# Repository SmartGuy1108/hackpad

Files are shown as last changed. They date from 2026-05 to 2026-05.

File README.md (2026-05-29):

# hackpad

My Hackpad is a 9 key macropad that uses 9 keyboard switches, a 0.96in oled screen, a xiao rp2040, 9 rgb leds, and a ATtiny85 for the leds. I made a PCB for this which can be found in the repo. It includes the gerber and drill files. My total price for this project was around $40 I used AliExpress to source the components for cheap and I used JLPCB for the PCB. The point of this was to make a maacropad that was cool and could be used for custom purposes instead of using the defualt layout. It works by making the Xiao do all the proccesing for the keys and the ATtiny doing all the led controls while being powered by the Xiao. I considered adding a usb C port for the ATtiny but decided against it to keep it all connected using one usb C so it looks clean. The total cost was around $48 I made a custom case that has a big hole for all the 9 keys because I didn't want they keycaps to get stuck on the lid. Here is the link to the OnShape project: https://cad.onshape.com/documents/e6c91fd51721781c7e785687/w/94b65f4af145f619cdb675ed/e/b2b440a0c79fd98d3f7bde3f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. The lid connects to the body using "rails" in the body. I also added a hole on the top for the OLED. I added circles on each corner of the pcb groove to make sure it stayed in place. Here is a image of the case: 

          






Some Items I used were:

|#  |Component |Quantity|Price |Supplier  |Link |
|---|---|---|---|---|---|
|1  |XDA Profile PBT Blank Black Keycaps (MX compatible 10pcs)|10 |included|AliExpress|https://www.aliexpress.us/item/3256805328092200.html |
|2  |ATtiny85-20PU DIP-8 AVR Microcontroller |1 |included|AliExpress|https://www.aliexpress.us/item/3256808555620766.html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  |
|3  |SSD1306 0.96in 128x64 OLED Display (I2C white 3pcs) |1 |included|AliExpress|https://www.aliexpress.us/item/3256805899077405.html |
|4  |WS2812B 5mm RGB Through-hole LED (5V diffused 10pcs) |9 |included|AliExpress|https://www.aliexpress.us/item/3256806040849067.html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|
|5  |Outemu Blue 3-Pin MX Switches (10pcs) |10 |included|AliExpress|https://www.aliexpress.us/item/3256803795058460.html |
|6  |Custom PCB 2 layer black 5pcs (JLCPCB) |5 |$9.30 |JLCPCB |N/A |
|7  |AliExpress Subtotal |- |- |$11.02 |- |
|8  |AliExpress Total |- |- |$11.02 |- |
|9  |PCB + Shipping |- |- |$12.00 |- |
|10 |Grand Total |- |- |$23.02 |- |

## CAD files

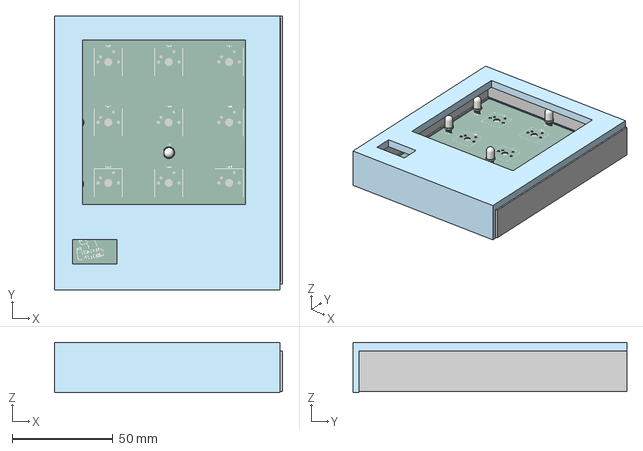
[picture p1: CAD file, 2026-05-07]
FINAL-MODEL/keyboard-together-(3mf).3mf
113.4 x 136.0 x 25.0 mm

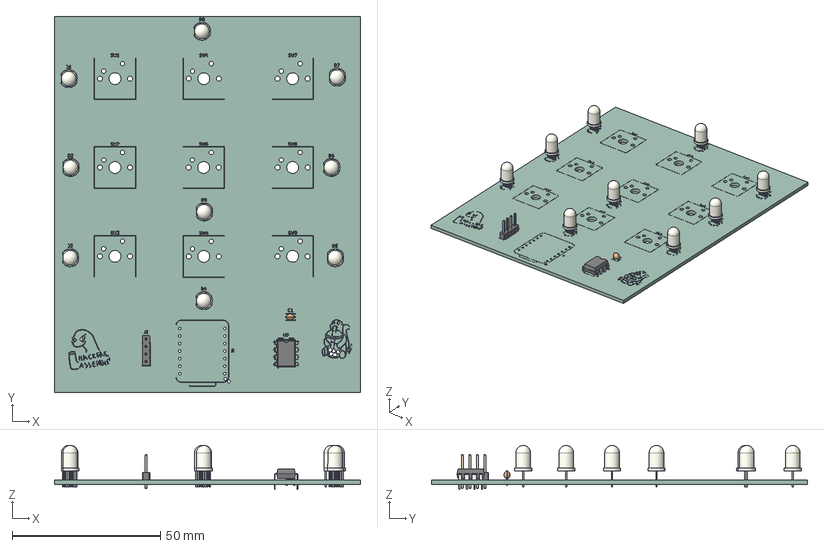
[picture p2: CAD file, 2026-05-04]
PCB/keyboard.step
103.5 x 127.0 x 14.9 mm
LED_D5.0mm-4_RGB x 9
DIP-8_W7.62mm
PinHeader_1x04_P2.54mm_Vertical
C_Disc_D3.0mm_W2.0mm_P2.50mm
keyboard_silkscreen
keyboard_PCB

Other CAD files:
Case/case-with-honeycombs.step
Case/keyboard-case.step
Case/case-with-honeycombs.stl
Case/keyboard-case.stl
FINAL-MODEL/EVERYTHING.f3d

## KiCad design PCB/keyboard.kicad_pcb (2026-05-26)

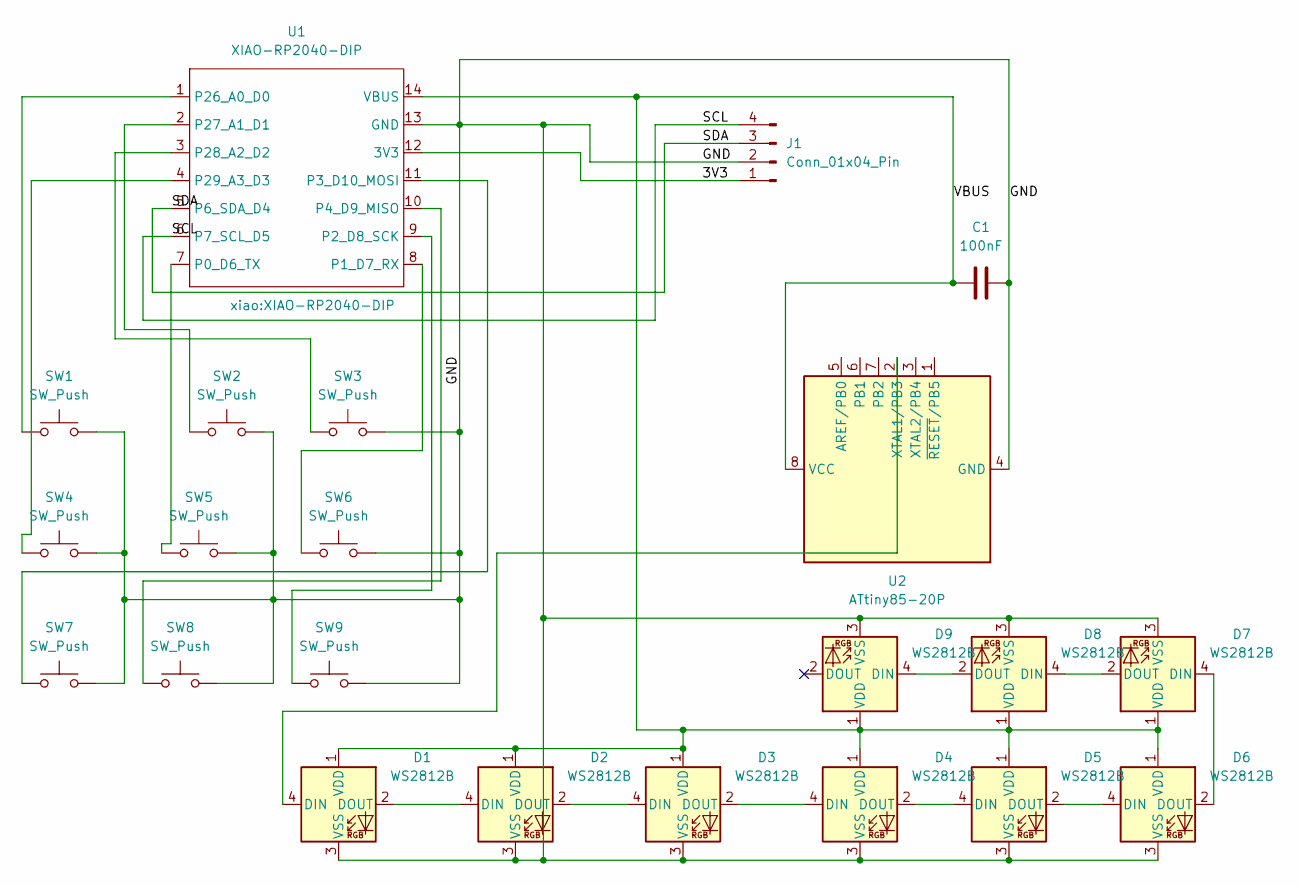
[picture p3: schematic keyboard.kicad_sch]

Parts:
C1: 100nF; C_Disc_D3.0mm_W2.0mm_P2.50mm
D1, D2, D3, D4, D5, D6, D7, D8, D9: WS2812B; LED_D5.0mm-4_RGB
J1: Conn_01x04_Pin; PinHeader_1x04_P2.54mm_Vertical
SW1, SW2, SW3, SW4, SW5, SW6, SW7, SW8, SW9: SW_Push; SW_Cherry_MX_1.00u_PCB
U1: XIAO-RP2040-DIP
U2: ATtiny85-20P; DIP-8_W7.62mm

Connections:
/3V3: J1.1, U1.12 (3V3)
/GND: C1.2, D1.3 (VSS), D2.3 (VSS), D3.3 (VSS), D4.3 (VSS), D5.3 (VSS), D6.3 (VSS), D7.3 (VSS), D8.3 (VSS), D9.3 (VSS), J1.2, SW1.2, SW2.2, SW3.2, SW4.2, SW5.2, SW6.2, SW7.2, SW8.2, SW9.2, U1.13 (GND), U2.4 (GND)
/SCL: J1.4, U1.6 (P7_SCL_D5)
/SDA: J1.3, U1.5 (P6_SDA_D4)
/VBUS: C1.1, D1.1 (VDD), D2.1 (VDD), D3.1 (VDD), D4.1 (VDD), D5.1 (VDD), D6.1 (VDD), D7.1 (VDD), D8.1 (VDD), D9.1 (VDD), U1.14 (VBUS), U2.8 (VCC)
unnamed: D1.4 (DIN), U2.2 (XTAL1/PB3)
unnamed: D1.2 (DOUT), D2.4 (DIN)
unnamed: D2.2 (DOUT), D3.4 (DIN)
unnamed: D3.2 (DOUT), D4.4 (DIN)
unnamed: D4.2 (DOUT), D5.4 (DIN)
unnamed: D5.2 (DOUT), D6.4 (DIN)
unnamed: D6.2 (DOUT), D7.4 (DIN)
unnamed: D7.2 (DOUT), D8.4 (DIN)
unnamed: D8.2 (DOUT), D9.4 (DIN)
unnamed: SW5.1, U1.7 (P0_D6_TX)
unnamed: SW6.1, U1.8 (P1_D7_RX)
unnamed: SW9.1, U1.9 (P2_D8_SCK)
unnamed: SW7.1, U1.11 (P3_D10_MOSI)
unnamed: SW8.1, U1.10 (P4_D9_MISO)
unnamed: SW1.1, U1.1 (P26_A0_D0)
unnamed: SW2.1, U1.2 (P27_A1_D1)
unnamed: SW3.1, U1.3 (P28_A2_D2)
unnamed: SW4.1, U1.4 (P29_A3_D3)

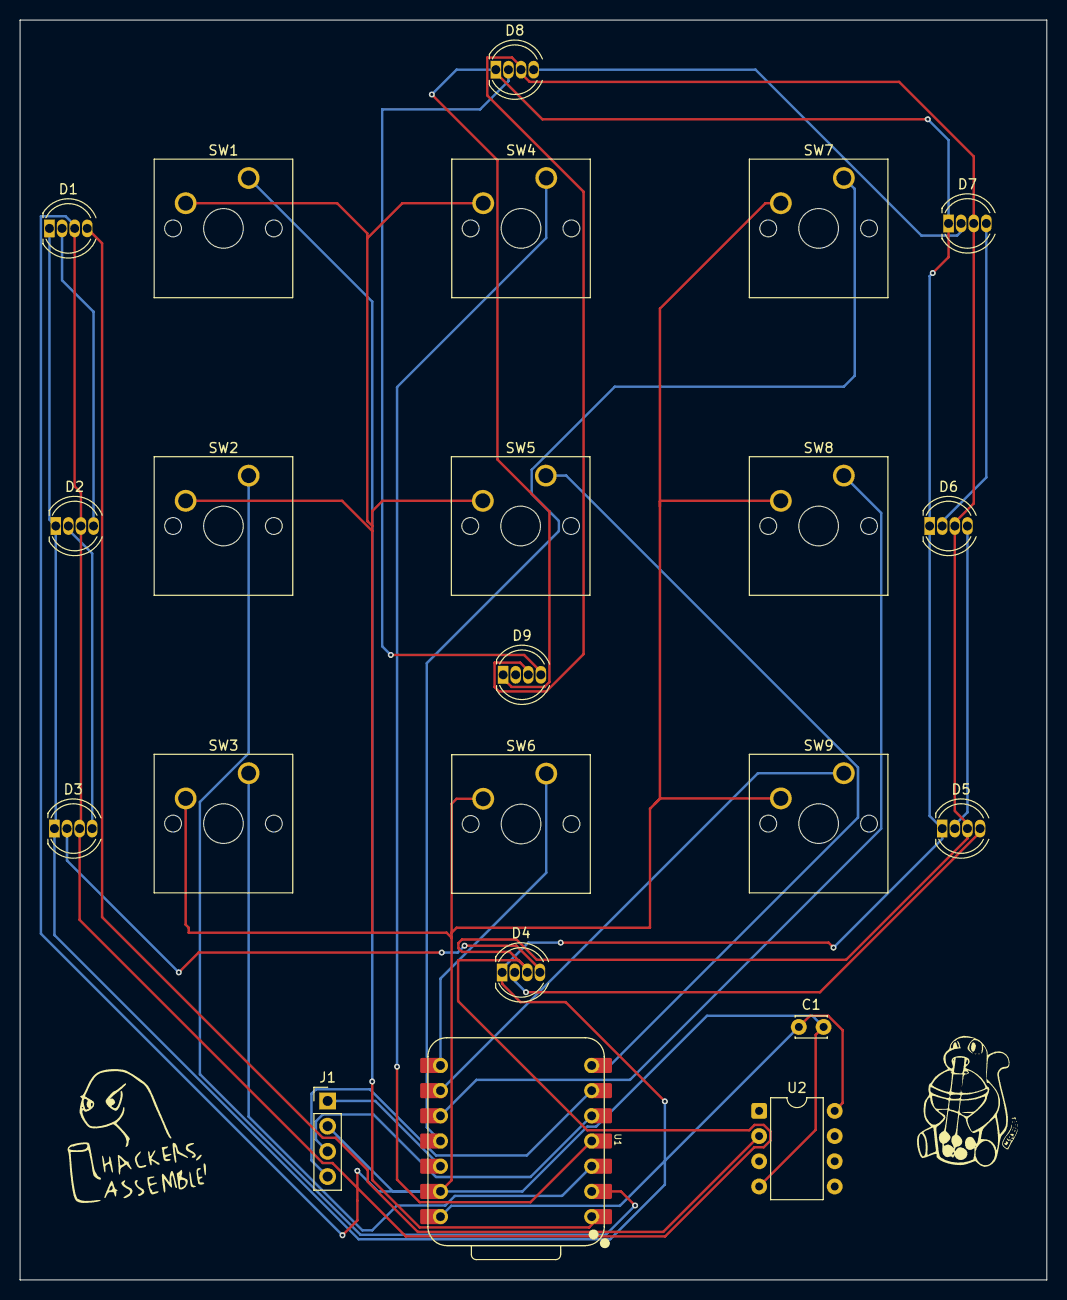
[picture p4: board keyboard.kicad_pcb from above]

Board: 2 copper layers, 103.5 x 127.0 mm, 22 parts (0 on the bottom side), 23 nets.

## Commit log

2026-05-02 Add BOM for 9-Key Macropad with cost summary
    Added a Bill of Materials for a 9-Key Macropad, including components, quantities, prices, suppliers, and links.
    [bom.csv]
2026-05-02 Fix formatting for WS2812B LEDs entry in bom.csv
2026-05-02 Clean up BOM by removing notes and header
    Removed unnecessary notes and header from BOM.
    [bom.csv]
2026-05-02 Modify SSD1306 OLED Display description in bom.csv
    Updated the description of the SSD1306 OLED Display in the BOM.
    [bom.csv]
2026-05-02 Convert BOM to CSV format with cost summary
    Updated the bill of materials to a CSV format with cost summary.
    [bom.csv]
2026-05-02 Modify bom.csv to add placeholders for costs
    Updated cost entries in bom.csv to include placeholders for additional information.
    [bom.csv]
2026-05-02 Remove unnecessary columns from bom.csv
    [bom.csv]
2026-05-04 Add LED control for rainbow and breathing effects
2026-05-04 Enhance README with custom case details
    Expanded description of the Hackpad project, detailing the custom case design and features.
2026-05-04 Add image of the Hackpad case to README
    Updated the README to include an image of the case.
2026-05-04 Change PCB shipping cost to $12.00
    Updated PCB fabrication and shipping cost in BOM.
    [bom.csv]
2026-05-05 Include images of the macropad case in README
    Added images of the custom case for the macropad.
2026-05-05 Update README with new image of custom case
    Added an additional image of the custom case for the macropad.
2026-05-05 Update README with new project case images
    Added an additional image of the project case to the README.
2026-05-07 Update README with additional case image
    Added an image of the custom case for the macropad.
2026-05-09 Update bom.csv by removing duplicates and adjusting totals
    Removed duplicate entries and updated totals.
    [bom.csv]
2026-05-09 Adjust AliExpress subtotal in bom.csv
    Updated AliExpress subtotal to reflect new total.
    [bom.csv]
2026-05-09 Fix link for WS2812B RGB LED in bom.csv
    Updated the link for WS2812B LED in the BOM.
    [bom.csv]
2026-05-09 Change price of Custom PCB in bom.csv
    Updated the price of Custom PCB from $5.00 to $9.30.
    [bom.csv]
2026-05-09 Update component links and pricing in bom.csv
    Updated the AliExpress link for the ATtiny85-20PU and adjusted the subtotal and grand total values.
    [bom.csv]
2026-05-17 Rename keyboard-case (1).stl to keyboard-case.stl
    [keyboard-case.stl]
